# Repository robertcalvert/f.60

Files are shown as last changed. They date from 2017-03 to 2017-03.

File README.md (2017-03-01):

f.60
=========

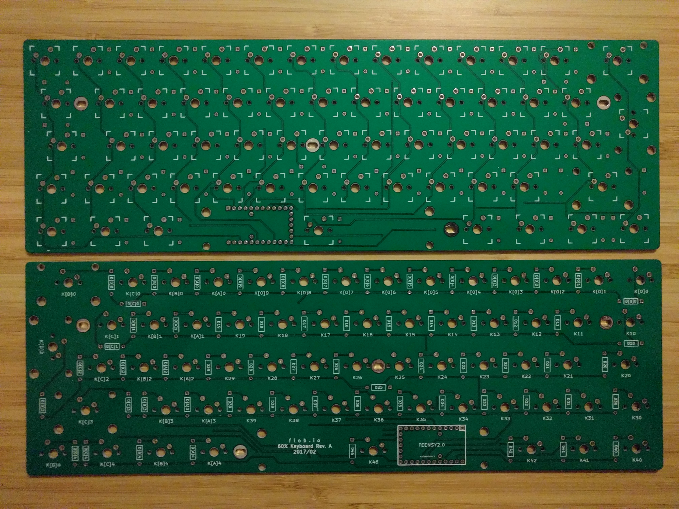
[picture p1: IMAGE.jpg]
f.60


About
-----

The f.60 is an open hardware 60% mechanical keyboard.

The board has a standard 62 key ISO layout designed for [Cherry MX](https://deskthority.net/wiki/Cherry_MX) switches. To avoid [ghosting](https://deskthority.net/wiki/Rollover,_blocking_and_ghosting#Ghosting) each switch has an associated diode. The [1N4148](https://en.wikipedia.org/wiki/1N4148_signal_diode) is a common choice; however any signal diode should work.

The board is designed for a [Teensy 2.0](https://www.pjrc.com/teensy/index.html) micro controller.

Repository Contents
-------------------
* **/hardware** - The KiCad design files
* **/firmware** - The TMK firmware files

Revisions
---------
* [Rev. A](https://github.com/robertcalvert/f.60/releases/tag/Rev.A)

License Information
-------------------

(c) 2017 Robert Calvert

The hardware is released under [Creative Commons ShareAlike 4.0 International](https://creativecommons.org/licenses/by-sa/4.0/).
The firmware is released under the [GNU General Public License V2](https://www.gnu.org/licenses/gpl-2.0.html) 

Distributed as-is; no warranty is given.

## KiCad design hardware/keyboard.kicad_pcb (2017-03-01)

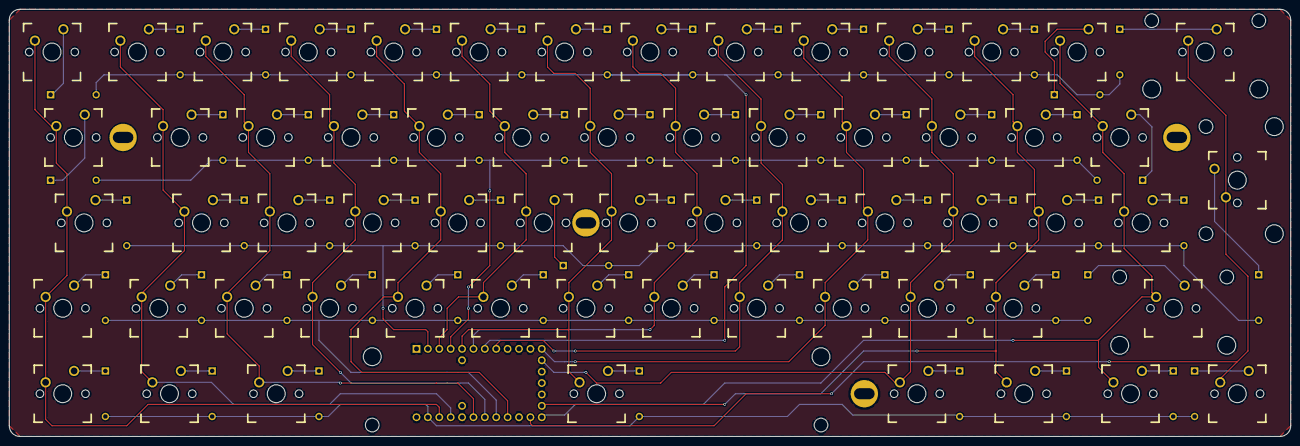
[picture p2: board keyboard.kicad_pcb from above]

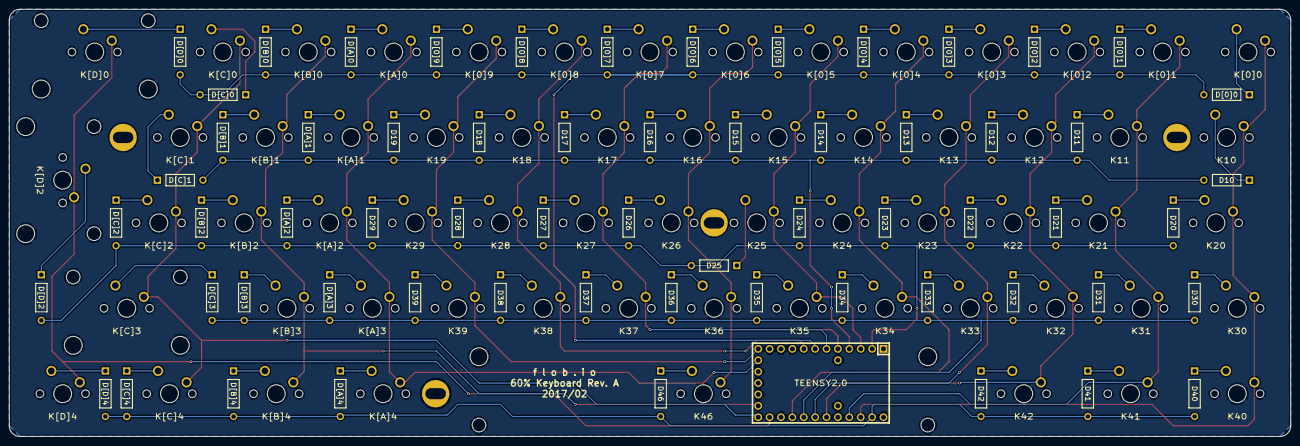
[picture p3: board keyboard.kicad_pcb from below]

Board: 2 copper layers, 285.8 x 95.3 mm, 129 parts (63 on the bottom side), 81 nets.

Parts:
D10, D11, D12, D13, D14, D15, D16, D17, D18, D19, D20, D21, D22, D23, D24, D25, D26, D27, D28, D29, D30, D31, D32, D33, D34, D35, D36, D37, D38, D39, D40, D41, D42, D46: D; DIODE
D[0]0, D[0]1, D[0]2, D[0]3, D[0]4, D[0]5, D[0]6, D[0]7, D[0]8, D[0]9: D; DIODE
D[A]0, D[A]1, D[A]2, D[A]3, D[A]4: D; DIODE
D[B]0, D[B]1, D[B]2, D[B]3, D[B]4: D; DIODE
D[C]0, D[C]1, D[C]2, D[C]3, D[C]4: D; DIODE
D[D]0, D[D]2, D[D]4: D; DIODE
K10: Tab; CHERRY_PCB_150H
K11: Q; CHERRY_PCB_100H
K12: W; CHERRY_PCB_100H
K13: E; CHERRY_PCB_100H
K14: R; CHERRY_PCB_100H
K15: T; CHERRY_PCB_100H
K16: Y; CHERRY_PCB_100H
K17: U; CHERRY_PCB_100H
K18: I; CHERRY_PCB_100H
K19: O; CHERRY_PCB_100H
K20: CapsLock; CHERRY_PCB_175H
K21: A; CHERRY_PCB_100H
K22: S; CHERRY_PCB_100H
K23: D; CHERRY_PCB_100H
K24: F; CHERRY_PCB_100H
K25: G; CHERRY_PCB_100H
K26: H; CHERRY_PCB_100H
K27: J; CHERRY_PCB_100H
K28: K; CHERRY_PCB_100H
K29: L; CHERRY_PCB_100H
K30: LShift; CHERRY_PCB_125H
K31: \; CHERRY_PCB_100H
K32: Z; CHERRY_PCB_100H
K33: X; CHERRY_PCB_100H
K34: C; CHERRY_PCB_100H
K35: V; CHERRY_PCB_100H
K36: B; CHERRY_PCB_100H
K37: N; CHERRY_PCB_100H
K38: M; CHERRY_PCB_100H
K39: ,; CHERRY_PCB_100H
K40: LCtrl; CHERRY_PCB_125H
K41: LSuper; CHERRY_PCB_125H
K42: LAlt; CHERRY_PCB_125H
K46: Space; CHERRY_PCB_625H
K[0]0: Esc; CHERRY_PCB_100H
K[0]1: 1; CHERRY_PCB_100H
K[0]2: 2; CHERRY_PCB_100H
K[0]3: 3; CHERRY_PCB_100H
K[0]4: 4; CHERRY_PCB_100H
K[0]5: 5; CHERRY_PCB_100H
K[0]6: 6; CHERRY_PCB_100H
K[0]7: 7; CHERRY_PCB_100H
K[0]8: 8; CHERRY_PCB_100H
K[0]9: 9; CHERRY_PCB_100H
K[A]0: 0; CHERRY_PCB_100H
K[A]1: P; CHERRY_PCB_100H
K[A]2: ;; CHERRY_PCB_100H
K[A]3: .; CHERRY_PCB_100H
K[A]4: RAltGr; CHERRY_PCB_125H
K[B]0: -; CHERRY_PCB_100H
K[B]1: [; CHERRY_PCB_100H
K[B]2: '; CHERRY_PCB_100H
K[B]3: /; CHERRY_PCB_100H
K[B]4: RSuper; CHERRY_PCB_125H
K[C]0: =; CHERRY_PCB_100H
K[C]1: ]; CHERRY_PCB_100H
K[C]2: #; CHERRY_PCB_100H
K[C]3: RShift; CHERRY_PCB_275H
K[C]4: Menu; CHERRY_PCB_125H
K[D]0: Backspace; CHERRY_PCB_200H
K[D]2: Enter; CHERRY_PCB_ISOR
K[D]4: RCtrl; CHERRY_PCB_125H
MH1, MH2, MH3, MH4: Poker_oval_hole
U1: TEENSY2.0; Teensy_20

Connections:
/C0: K10.2, K20.2, K30.2, K40.2, K[0]0.2, U1.27
/C1: K11.2, K21.2, K31.2, K41.2, K[0]1.2, U1.26
/C2: K12.2, K22.2, K32.2, K42.2, K[0]2.2, U1.24
/C3: K13.2, K23.2, K33.2, K[0]3.2, U1.23
/C4: K14.2, K24.2, K34.2, K[0]4.2, U1.21
/C5: K15.2, K25.2, K35.2, K[0]5.2, U1.3
/C6: K16.2, K26.2, K36.2, K46.2, K[0]6.2, U1.5
/C7: K17.2, K27.2, K37.2, K[0]7.2, U1.6
/C8: K18.2, K28.2, K38.2, K[0]8.2, U1.8
/C9: K19.2, K29.2, K39.2, K[0]9.2, U1.12
/C10: K[A]0.2, K[A]1.2, K[A]2.2, K[A]3.2, K[A]4.2, U1.13
/C11: K[B]0.2, K[B]1.2, K[B]2.2, K[B]3.2, K[B]4.2, U1.17
/C12: K[C]0.2, K[C]1.2, K[C]2.2, K[C]3.2, K[C]4.2, U1.18
/C13: K[D]0.2, K[D]2.2, K[D]4.2, U1.19
/R0: D[0]0.1, D[0]1.1, D[0]2.1, D[0]3.1, D[0]4.1, D[0]5.1, D[0]6.1, D[0]7.1, D[0]8.1, D[0]9.1, D[A]0.1, D[B]0.1, D[C]0.1, D[D]0.1, U1.7
/R1: D10.1, D11.1, D12.1, D13.1, D14.1, D15.1, D16.1, D17.1, D18.1, D19.1, D[A]1.1, D[B]1.1, D[C]1.1, U1.4
/R2: D20.1, D21.1, D22.1, D23.1, D24.1, D25.1, D26.1, D27.1, D28.1, D29.1, D[A]2.1, D[B]2.1, D[C]2.1, D[D]2.1, U1.2
/R3: D30.1, D31.1, D32.1, D33.1, D34.1, D35.1, D36.1, D37.1, D38.1, D39.1, D[A]3.1, D[B]3.1, D[C]3.1, U1.22
/R4: D40.1, D41.1, D42.1, D46.1, D[A]4.1, D[B]4.1, D[C]4.1, D[D]4.1, U1.28
unnamed: D10.2, K10.1
unnamed: D11.2, K11.1
unnamed: D12.2, K12.1
unnamed: D13.2, K13.1
unnamed: D14.2, K14.1
unnamed: D15.2, K15.1
unnamed: D16.2, K16.1
unnamed: D17.2, K17.1
unnamed: D18.2, K18.1
unnamed: D19.2, K19.1
unnamed: D20.2, K20.1
unnamed: D21.2, K21.1
unnamed: D22.2, K22.1
unnamed: D23.2, K23.1
unnamed: D24.2, K24.1
unnamed: D25.2, K25.1
unnamed: D26.2, K26.1
unnamed: D27.2, K27.1
unnamed: D28.2, K28.1
unnamed: D29.2, K29.1
unnamed: D30.2, K30.1
unnamed: D31.2, K31.1
unnamed: D32.2, K32.1
unnamed: D33.2, K33.1
unnamed: D34.2, K34.1
unnamed: D35.2, K35.1
unnamed: D36.2, K36.1
unnamed: D37.2, K37.1
unnamed: D38.2, K38.1
unnamed: D39.2, K39.1
unnamed: D40.2, K40.1
unnamed: D41.2, K41.1
unnamed: D42.2, K42.1
unnamed: D46.2, K46.1
unnamed: D[0]0.2, K[0]0.1
unnamed: D[0]1.2, K[0]1.1
unnamed: D[0]2.2, K[0]2.1
unnamed: D[0]3.2, K[0]3.1
unnamed: D[0]4.2, K[0]4.1
unnamed: D[0]5.2, K[0]5.1
unnamed: D[0]6.2, K[0]6.1
unnamed: D[0]7.2, K[0]7.1
unnamed: D[0]8.2, K[0]8.1
unnamed: D[0]9.2, K[0]9.1
unnamed: D[A]0.2, K[A]0.1
unnamed: D[A]1.2, K[A]1.1
unnamed: D[A]2.2, K[A]2.1
unnamed: D[A]3.2, K[A]3.1
unnamed: D[A]4.2, K[A]4.1
unnamed: D[B]0.2, K[B]0.1
unnamed: D[B]1.2, K[B]1.1
unnamed: D[B]2.2, K[B]2.1
unnamed: D[B]3.2, K[B]3.1
unnamed: D[B]4.2, K[B]4.1
unnamed: D[C]0.2, K[C]0.1
unnamed: D[C]1.2, K[C]1.1
unnamed: D[C]2.2, K[C]2.1
unnamed: D[C]3.2, K[C]3.1
unnamed: D[C]4.2, K[C]4.1
unnamed: D[D]0.2, K[D]0.1
unnamed: D[D]2.2, K[D]2.1
unnamed: D[D]4.2, K[D]4.1

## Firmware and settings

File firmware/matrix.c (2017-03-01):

/*
Copyright 2017 Robert Calvert <robert.calvert.io>
Copyright 2012 Jun Wako <wakojun@gmail.com>

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
You should have received a copy of the GNU General Public License
along with this program.  If not, see <http://www.gnu.org/licenses/>.
*/

/*
 * scan matrix
 */
#include <stdint.h>
#include <stdbool.h>
#include <avr/io.h>
#include <util/delay.h>
#include "print.h"
#include "debug.h"
#include "util.h"
#include "matrix.h"


#ifndef DEBOUNCE
#   define DEBOUNCE	5
#endif
static uint8_t debouncing = DEBOUNCE;

/* matrix state(1:on, 0:off) */
static matrix_row_t matrix[MATRIX_ROWS];
static matrix_row_t matrix_debouncing[MATRIX_ROWS];

static matrix_row_t read_cols(void);
static void init_cols(void);
static void unselect_rows(void);
static void select_row(uint8_t row);


inline
uint8_t matrix_rows(void)
{
    return MATRIX_ROWS;
}

inline
uint8_t matrix_cols(void)
{
    return MATRIX_COLS;
}

void matrix_init(void)
{
    // initialize row and col
    unselect_rows();
    init_cols();

    // initialize matrix state: all keys off
    for (uint8_t i=0; i < MATRIX_ROWS; i++) {
        matrix[i] = 0;
        matrix_debouncing[i] = 0;
    }
}

uint8_t matrix_scan(void)
{
    for (uint8_t i = 0; i < MATRIX_ROWS; i++) {
        select_row(i);
        _delay_us(30);  // without this wait read unstable value.
        matrix_row_t cols = read_cols();
        if (matrix_debouncing[i] != cols) {
            matrix_debouncing[i] = cols;
            if (debouncing) {
                debug("bounce!: "); debug_hex(debouncing); debug("\n");
            }
            debouncing = DEBOUNCE;
        }
        unselect_rows();
    }

    if (debouncing) {
        if (--debouncing) {
            _delay_ms(1);
        } else {
            for (uint8_t i = 0; i < MATRIX_ROWS; i++) {
                matrix[i] = matrix_debouncing[i];
            }
        }
    }

    return 1;
}

bool matrix_is_modified(void)
{
    if (debouncing) return false;
    return true;
}

inline
bool matrix_is_on(uint8_t row, uint8_t col)
{
    return (matrix[row] & ((matrix_row_t)1<<col));
}

inline
matrix_row_t matrix_get_row(uint8_t row)
{
    return matrix[row];
}

void matrix_print(void)
{
    print("\nr/c 0123456789ABCDEF\n");
    for (uint8_t row = 0; row < MATRIX_ROWS; row++) {
        phex(row); print(": ");
        pbin_reverse16(matrix_get_row(row));
        print("\n");
    }
}

uint8_t matrix_key_count(void)
{
    uint8_t count = 0;
    for (uint8_t i = 0; i < MATRIX_ROWS; i++) {
        count += bitpop16(matrix[i]);
    }
    return count;
}

/* Column pin configuration
 * col: 0   1   2   3   4   5   6   7   8   9   10  11  12  13
 * pin: F1  F4  F6  F7  B5  B1  B3  B7  D1  C7  D5  D4  D6  D7
 */
 static void init_cols(void)
{
    DDRB &= ~(1<<7 | 1<<5 | 1<<3| 1<<1);
    PORTB |= (1<<7 | 1<<5 | 1<<3| 1<<1);
    DDRC &= ~(1<<7);
    PORTC |= (1<<7);
    DDRD &= ~(1<<7 | 1<<6 | 1<<5| 1<<4| 1<<1);
    PORTD |= (1<<7 | 1<<6 | 1<<5| 1<<4| 1<<1);
    DDRF &= ~(1<<7 | 1<<6 | 1<<4| 1<<1);
    PORTF |= (1<<7 | 1<<6 | 1<<4| 1<<1);
}

static matrix_row_t read_cols(void)
{
  return (PINF&(1<<1) ? 0 : (1<<0)) |
         (PINF&(1<<4) ? 0 : (1<<1)) |
         (PINF&(1<<6) ? 0 : (1<<2)) |
         (PINF&(1<<7) ? 0 : (1<<3)) |
         (PINB&(1<<5) ? 0 : (1<<4)) |
         (PINB&(1<<1) ? 0 : (1<<5)) |
         (PINB&(1<<3) ? 0 : (1<<6)) |
         (PINB&(1<<7) ? 0 : (1<<7)) |
         (PIND&(1<<1) ? 0 : (1<<8)) |
         (PINC&(1<<7) ? 0 : (1<<9)) |
         (PIND&(1<<5) ? 0 : (1<<10)) |
         (PIND&(1<<4) ? 0 : (1<<11)) |
         (PIND&(1<<6) ? 0 : (1<<12)) |
         (PIND&(1<<7) ? 0 : (1<<13));
}

/* Row pin configuration
 * row: 0   1   2   3   4
 * pin: D0  B2  B0  B6  F0
 */
static void unselect_rows(void)
{
    DDRB &= ~(1<<0 | 1<<2 | 1<<6);
    PORTB |= (1<<0 | 1<<2 | 1<<6);
    DDRD &= ~(1<<0);
    PORTD |= (1<<0);
    DDRF &= ~(1<<0);
    PORTF |= (1<<0);
}

static void select_row(uint8_t row)
{
    switch (row) {
        case 0:
            DDRD  |= (1<<0);
            PORTD &= ~(1<<0);
            break;
        case 1:
            DDRB  |= (1<<2);
            PORTB &= ~(1<<2);
            break;
        case 2:
            DDRB  |= (1<<0);
            PORTB &= ~(1<<0);
            break;
        case 3:
            DDRB  |= (1<<6);
            PORTB &= ~(1<<6);
            break;
        case 4:
            DDRF  |= (1<<0);
            PORTF &= ~(1<<0);
            break;
    }
}

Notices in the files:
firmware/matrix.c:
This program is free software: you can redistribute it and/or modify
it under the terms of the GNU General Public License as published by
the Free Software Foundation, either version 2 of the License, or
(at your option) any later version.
